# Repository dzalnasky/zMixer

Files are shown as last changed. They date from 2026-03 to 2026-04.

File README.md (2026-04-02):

# zMixer
zMixer is a USB-C programmable, 0-4GHz IF to 5-10.4GHz RF upconverting/downconverting RF mixer with dedicated LO chip generating 0-6.4GHz. Perfect for radios with operating frequencies up to 4GHz that want to work with higher frequency bands. 
# Key Components
* Texas Instruments LMX2572 Frequency Synthesizer
  * Drop in replacements include the LMX2592 (up to 9.8GHz), LMX2594 (up to 15GHz), and LMX2595 (up to 20GHz) for higher LO frequency generation **(May require different RF mixer IC)*
* Microchip MCP2210 USB to SPI Interface
* Analog Devices HMC220B RF Mixer
  * Drop in replacement includes HMC218B (3.5-8GHz RF/LO, 1.5GHz IF)
# Block Diagram

# Schematic


# PCB
pcb_3d

pcb_2d

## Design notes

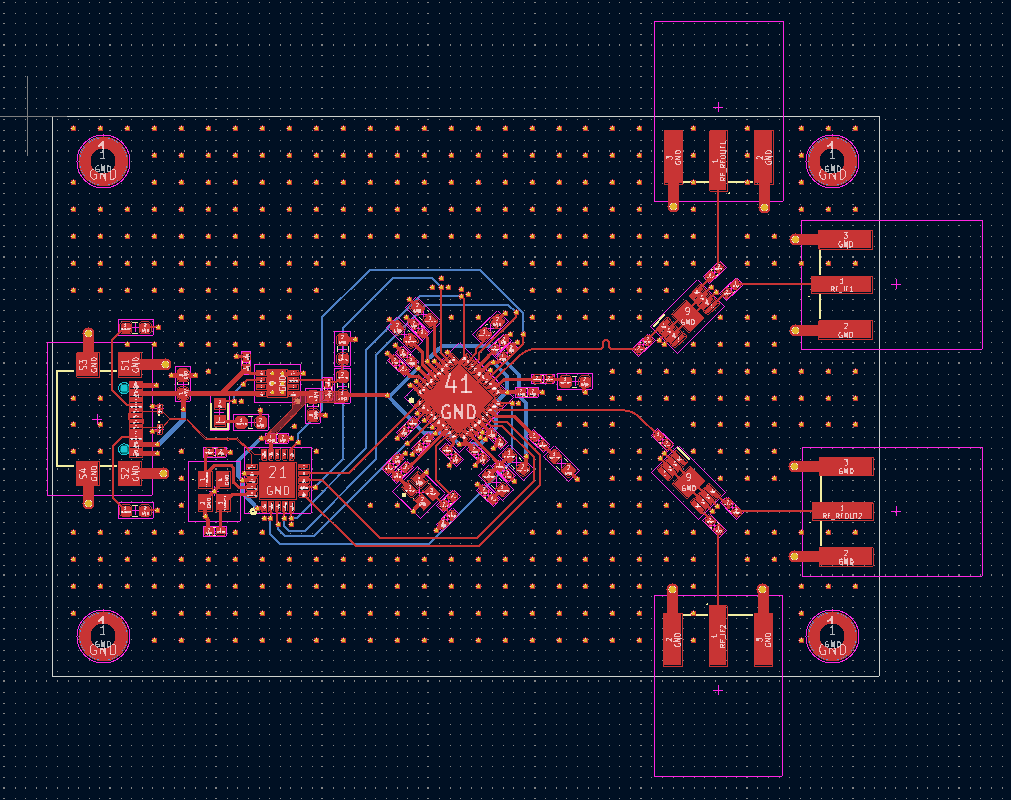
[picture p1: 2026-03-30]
Mixer_KiCAD/Mixer/pcb_2d.PNG

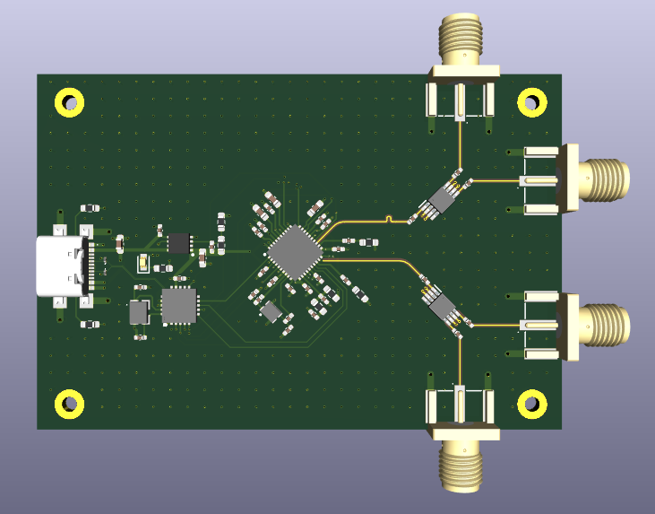
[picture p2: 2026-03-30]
Mixer_KiCAD/Mixer/pcb_3d.PNG

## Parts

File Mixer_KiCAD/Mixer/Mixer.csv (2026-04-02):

Reference | Qty | Value | DNP | Exclude from BOM | Exclude from Board | Footprint | Datasheet | Distributor Link | MPN
C1,C11,C12,C19 | 4 | 100n |  |  |  | Capacitor_SMD:C_0402_1005Metric_Pad0.74x0.62mm_HandSolder | https://www.mouser.com/datasheet/3/76/2/GRM155R70J104KA01_01A.pdf | https://www.mouser.com/ProductDetail/Murata-Electronics/GRM155R70J104KA01D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 | GRM155R70J104KA01D
C2,C3,C4,C5,C6,C7,C13,C16 | 8 | 20p |  |  |  | Capacitor_SMD:C_0402_1005Metric_Pad0.74x0.62mm_HandSolder | https://pim.murata.com/asset/pim4/ceramicCapacitorSMD/GCM1555C1H200JA16-01A-EN_PDF_CERAMICCAPACITORSMD | https://www.mouser.com/ProductDetail/Murata-Electronics/GCM1555C1H200JA16D | GCM1555C1H200JA16D
C8,C9,C10,C24,C31 | 5 | 1u |  |  |  | Capacitor_SMD:C_0402_1005Metric_Pad0.74x0.62mm_HandSolder | https://www.mouser.com/datasheet/3/76/2/GRT155C80J105KE01_01A.pdf | https://www.mouser.com/ProductDetail/Murata-Electronics/GRT155C80J105KE01D | GRT155C80J105KE01D
C14 | 1 | 560p |  |  |  | Capacitor_SMD:C_0402_1005Metric_Pad0.74x0.62mm_HandSolder | https://datasheets.kyocera-avx.com/KGM_X7R.pdf | https://www.mouser.com/ProductDetail/KYOCERA-AVX/04026C681KAT2A | 04026C681KAT2A
C15 | 1 | 1n5 |  |  |  | Capacitor_SMD:C_0402_1005Metric_Pad0.74x0.62mm_HandSolder | https://pim.murata.com/asset/pim4/ceramicCapacitorSMD/GRM1555C1H152GA01-01A-EN_PDF_CERAMICCAPACITORSMD | https://www.mouser.com/ProductDetail/Murata-Electronics/GRM1555C1H152GA01D | GRM1555C1H152GA01D
C17 | 1 | 120n |  |  |  | Capacitor_SMD:C_0402_1005Metric_Pad0.74x0.62mm_HandSolder | https://www.mouser.com/datasheet/3/76/3/GRM155R61A124ME19_01A.pdf | https://www.mouser.com/ProductDetail/Murata-Electronics/GRM155R61A124ME19D | GRM155R61A124ME19D
C18,C21,C23,C30,C33 | 5 | 10u |  |  |  | Capacitor_SMD:C_0603_1608Metric_Pad1.08x0.95mm_HandSolder | https://www.mouser.com/datasheet/3/76/2/GRM188R60J106ME47_61A.pdf | https://www.mouser.com/ProductDetail/Murata-Electronics/GRM188R60J106ME47D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 | GRM188R60J106ME47D
C20,C29 | 2 | 470n |  |  |  | Capacitor_SMD:C_0402_1005Metric_Pad0.74x0.62mm_HandSolder | https://www.mouser.com/datasheet/3/76/3/GRM155R61H474ME11_01A.pdf | https://www.mouser.com/ProductDetail/Murata-Electronics/GRM155R61H474ME11D | GRM155R61H474ME11D
C22,C32 | 2 | 10n |  |  |  | Capacitor_SMD:C_0402_1005Metric_Pad0.74x0.62mm_HandSolder | https://www.mouser.com/datasheet/3/76/1/GRM155R71E103JA01-01A.pdf | https://www.mouser.com/ProductDetail/Murata-Electronics/GRM155R71E103JA01J | GRM155R71E103JA01J
C25,C26 | 2 | 3n |  |  |  | Capacitor_SMD:C_0402_1005Metric_Pad0.74x0.62mm_HandSolder | https://pim.murata.com/asset/pim4/ceramicCapacitorSMD/GRM1557U1A302JA01-01A-EN_PDF_CERAMICCAPACITORSMD | https://www.mouser.com/ProductDetail/Murata-Electronics/GRM1557U1A302JA01D?qs=MY6wChARw2y70SmNRdypAQ%3D%3D | GRM1557U1A302JA01D
C27,C28 | 2 | 4p |  |  |  | Capacitor_SMD:C_0402_1005Metric_Pad0.74x0.62mm_HandSolder | https://pim.murata.com/asset/pim4/ceramicCapacitorSMD/GCM1555C1H4R0BA16-01A-EN_PDF_CERAMICCAPACITORSMD | https://www.mouser.com/ProductDetail/Murata-Electronics/GCM1555C1H4R0BA16J | GCM1555C1H4R0BA16J
C34,C35 | 2 | 10p |  |  |  | Capacitor_SMD:C_0402_1005Metric_Pad0.74x0.62mm_HandSolder | https://pim.murata.com/asset/pim4/ceramicCapacitorSMD/GCM1555C1H100JA16-01A-EN_PDF_CERAMICCAPACITORSMD | https://www.mouser.com/ProductDetail/Murata-Electronics/GCM1555C1H100JA16J | GCM1555C1H100JA16J
D1,D2 | 2 | ESD8472MUT5G |  |  |  | SamacSys_Parts:X3DFN2-CASE152AF-ISSUE-A | https://www.onsemi.com/pub/Collateral/ESD8472-D.PDF | https://www.mouser.com/ProductDetail/onsemi/ESD8472MUT5G?qs=72ObqG5T4UZT1i%252BIC5Pouw%3D%3D | ESD8472MUT5G
H1,H2,H3,H4 | 4 | MountingHole_Pad |  | Excluded from BOM |  | MountingHole:MountingHole_2.2mm_M2_Pad_TopBottom | ~
IC1,IC3 | 2 | HMC220BMS8GETR |  |  |  | SamacSys_Parts:SOP65P490X110-9N | https://www.analog.com/media/en/technical-documentation/data-sheets/HMC220B.pdf | https://www.analog.com/HMC220B/datasheet | HMC220BMS8GETR
IC2 | 1 | LMX2572RHAT |  |  |  | SamacSys_Parts:QFN50P600X600X100-41N-D | http://www.ti.com/lit/gpn/lmx2572 | https://www.mouser.com/ProductDetail/Texas-Instruments/LMX2572RHAR?qs=j%252B1pi9TdxUZ5mDySBseH5A%3D%3D | LMX2572RHAR
IC4 | 1 | TPS74601PQWDRBRQ1 |  |  |  | SamacSys_Parts:SON65P300X300X100-9N-D | https://www.ti.com/lit/ds/symlink/tps746-q1.pdf?ts=1625472063654 | https://www.mouser.com/ProductDetail/Texas-Instruments/TPS74601PQWDRBRQ1 | TPS74601PQWDRBRQ1
IC5 | 1 | MCP2210-I_MQ |  |  |  | SamacSys_Parts:QFN65P500X500X100-21N-D | https://www.mouser.com/datasheet/3/282/1/MCP2210-Data-Sheet-DS20002288.pdf | https://www.mouser.com/ProductDetail/Microchip-Technology/MCP2210-I-MQ?qs=hort8UWU32pLWgskQOyvyg%3D%3D | MCP2210-I/MQ
J1,J2,J3,J4 | 4 | CONSMA020.062-G |  |  |  | SamacSys_Parts:CONSMA020062G | https://componentsearchengine.com/Datasheets/1/CONSMA020.062-G.pdf | https://www.mouser.com/ProductDetail/TE-Connectivity-Linx-Technologies/CONSMA020.062-G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 | CONSMA020.062-G
J5 | 1 | USB4940-00-A |  |  |  | SamacSys_Parts:USB494000A | https://gct.co/download?type=PDFDrawing&name=USB4940.pdf | https://www.mouser.com/ProductDetail/GCT/USB4940-00-A?qs=vcFyY%252BOcAyjpPzN1Hxr%2FVw%3D%3D | USB4940-00-A
LED1 | 1 | SML-D12U1WT86 |  |  |  | SamacSys_Parts:LEDC1608X65N | https://componentsearchengine.com/Datasheets/1/SML-D12U1WT86.pdf | https://www.mouser.com/ProductDetail/ROHM-Semiconductor/SML-D12U1WT86 | SML-D12U1WT86
R1,R2 | 2 | 50R |  |  |  | Resistor_SMD:R_0603_1608Metric_Pad0.98x0.95mm_HandSolder | https://www.vishay.com/doc?28758 | https://www.mouser.com/ProductDetail/Vishay/TNPW060350R0DEEA | TNPW060350R0DEEA
R3 | 1 | 330R |  |  |  | Resistor_SMD:R_0603_1608Metric_Pad0.98x0.95mm_HandSolder | https://www.vishay.com/doc?20132 | https://www.mouser.com/ProductDetail/Vishay/RCA0603330RFKEASR | RCA0603330RFKEASR
R4 | 1 | 120R |  |  |  | Resistor_SMD:R_0603_1608Metric_Pad0.98x0.95mm_HandSolder | https://www.vishay.com/doc?28952 | https://www.mouser.com/ProductDetail/Vishay-Beyschlag/MCT0603MC1200FP500 | MCT0603MC1200FP500
R5,R6 | 2 | 5k1 |  |  |  | Resistor_SMD:R_0603_1608Metric_Pad0.98x0.95mm_HandSolder | https://www.vishay.com/docs/20035/dcrcwe3.pdf | https://www.mouser.com/ProductDetail/Vishay/CRCW06035K10FKEBC | CRCW06035K10FKEBC
R7 | 1 | 1M |  |  |  | Resistor_SMD:R_0603_1608Metric_Pad0.98x0.95mm_HandSolder | https://www.vishay.com/docs/20035/dcrcwe3.pdf | https://www.mouser.com/ProductDetail/Vishay/CRCW06031M00FKEAC | CRCW06031M00FKEAC
R8 | 1 | 140R |  |  |  | Resistor_SMD:R_0603_1608Metric_Pad0.98x0.95mm_HandSolder | https://www.vishay.com/docs/20035/dcrcwe3.pdf | https://www.mouser.com/ProductDetail/Vishay/CRCW0603140RFKEAC | CRCW0603140RFKEAC
R9 | 1 | 200k |  |  |  | Resistor_SMD:R_0603_1608Metric_Pad0.98x0.95mm_HandSolder | https://www.vishay.com/docs/20035/dcrcwe3.pdf | https://www.mouser.com/ProductDetail/Vishay/CRCW0603200KFKEBC | CRCW0603200KFKEBC
Y1 | 1 | ABM10W-50.0000MHZ-4-D1X-T3 |  |  |  | SamacSys_Parts:ABM10W240000MHZ8K1ZT3 | https://www.mouser.com/datasheet/3/184/1/ABM10W.pdf | https://www.mouser.com/ProductDetail/ABRACON/ABM10W-50.0000MHZ-4-D1X-T3?qs=5aG0NVq1C4yqd2TM%2F89nsQ%3D%3D | ABM10W-50.0000MHZ-4-D1X-T3
Y2 | 1 | ABM8G-12.000MHZ-18-D2Y-T |  |  |  | SamacSys_Parts:ABM8G12000MHZ18D2YT | https://www.mouser.com/datasheet/3/184/1/ABM8G.pdf | https://www.mouser.com/ProductDetail/ABRACON/ABM8G-12.000MHZ-18-D2Y-T?qs=3LVMET7lfiMArGND0L1Ksw%3D%3D | ABM8G-12.000MHZ-18-D2Y-T

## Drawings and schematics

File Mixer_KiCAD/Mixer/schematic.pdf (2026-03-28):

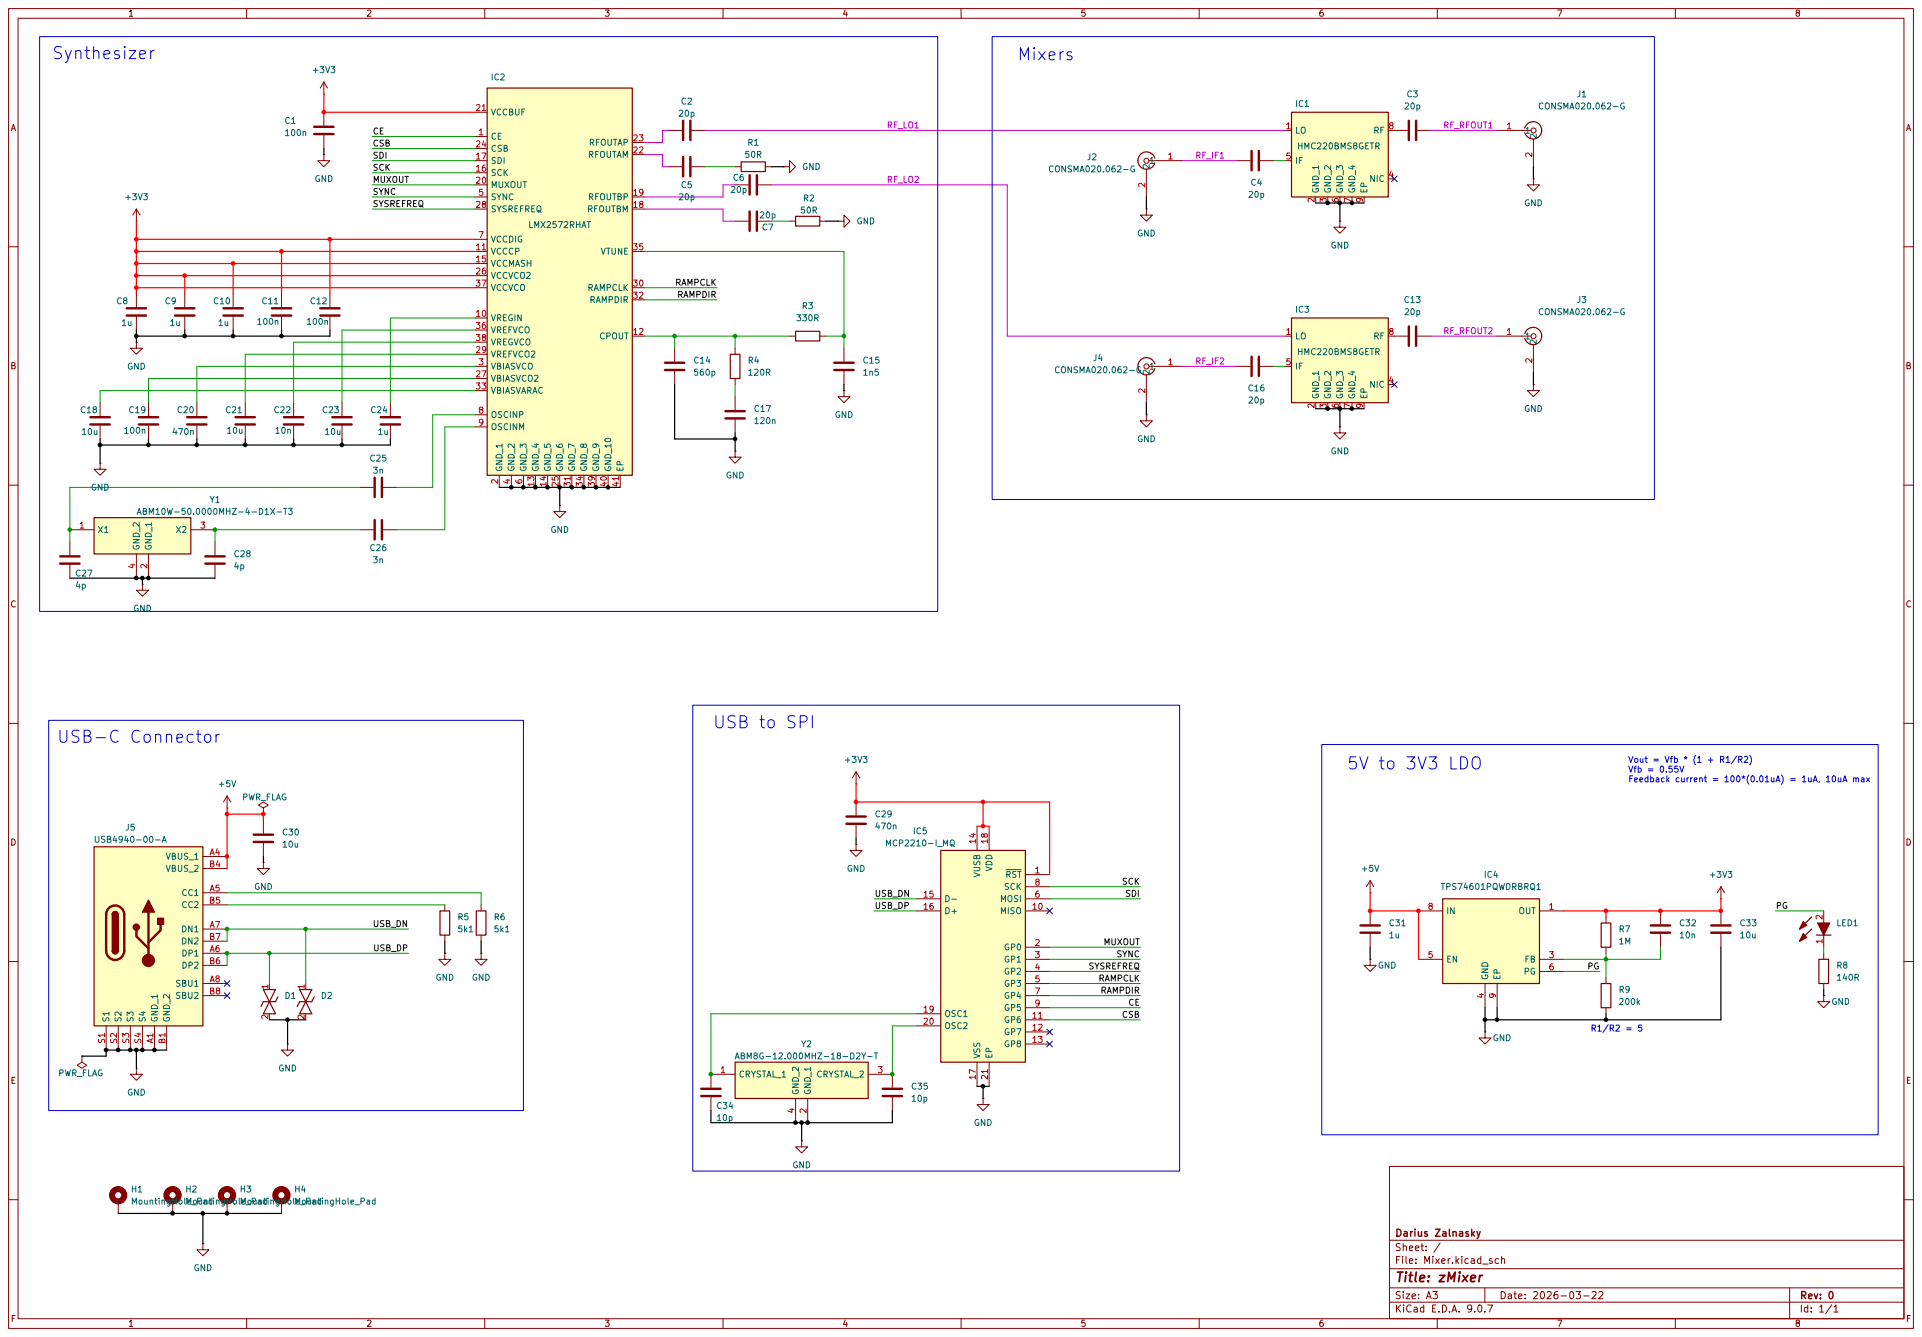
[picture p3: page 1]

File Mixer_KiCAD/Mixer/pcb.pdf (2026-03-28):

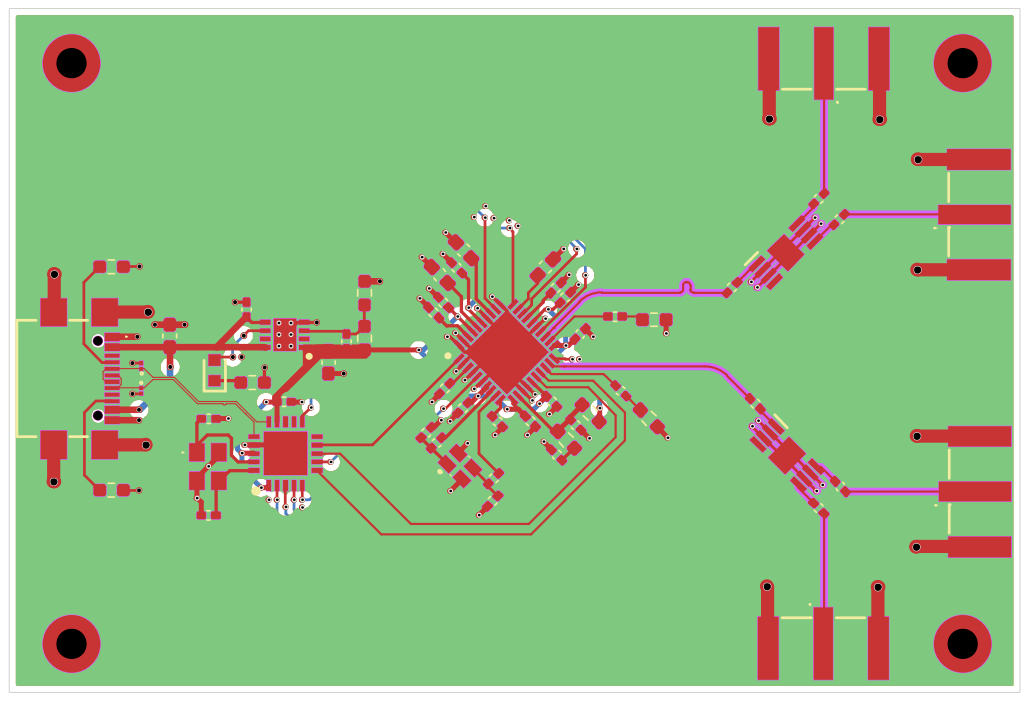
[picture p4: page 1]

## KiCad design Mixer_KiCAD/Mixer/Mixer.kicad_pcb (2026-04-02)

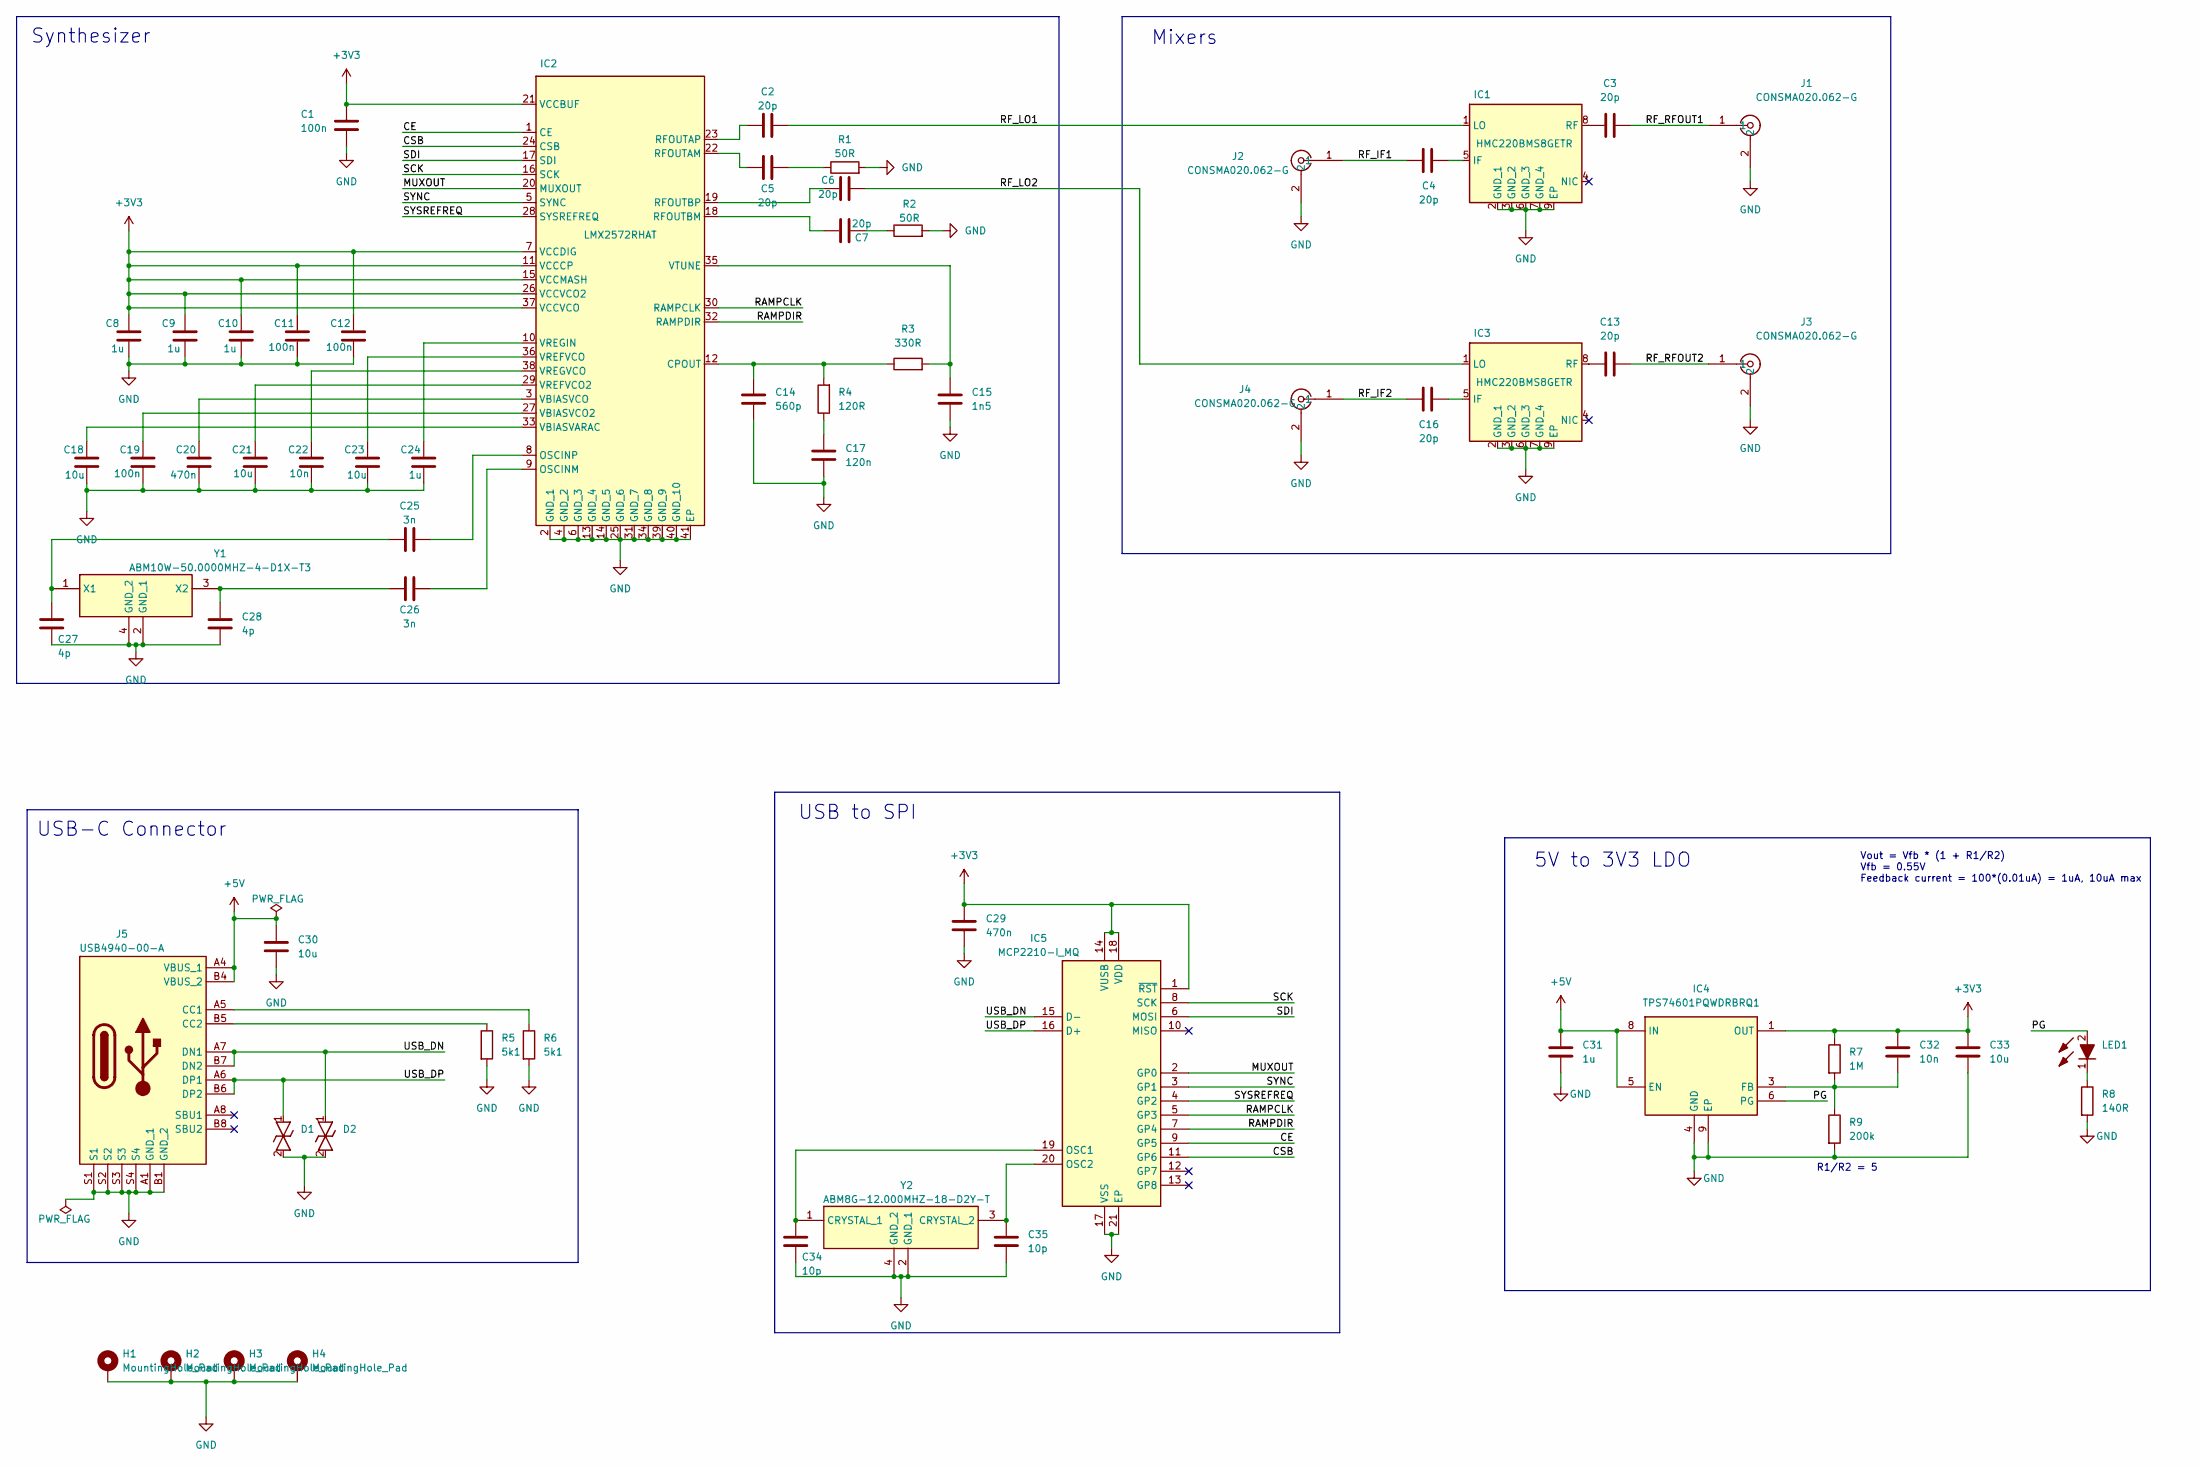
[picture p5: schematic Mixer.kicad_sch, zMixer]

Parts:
C1, C11, C12, C19: 100n; C_0402_1005Metric_Pad0.74x0.62mm_HandSolder; Voltage/Current Rating 6.3V
C2, C3, C4, C5, C6, C7, C13, C16: 20p; C_0402_1005Metric_Pad0.74x0.62mm_HandSolder
C8, C9, C10, C24: 1u; C_0402_1005Metric_Pad0.74x0.62mm_HandSolder; Voltage/Current Rating 6.3V
C14: 560p; C_0402_1005Metric_Pad0.74x0.62mm_HandSolder; Voltage/Current Rating 6.3V
C15: 1n5; C_0402_1005Metric_Pad0.74x0.62mm_HandSolder; Voltage/Current Rating 6.3V
C17: 120n; C_0402_1005Metric_Pad0.74x0.62mm_HandSolder; Voltage/Current Rating 6.3V
C18, C21, C23, C30: 10u; C_0603_1608Metric_Pad1.08x0.95mm_HandSolder; Voltage/Current Rating 6.3V
C20: 470n; C_0402_1005Metric_Pad0.74x0.62mm_HandSolder; Voltage/Current Rating 6.3V
C22: 10n; C_0402_1005Metric_Pad0.74x0.62mm_HandSolder; Voltage/Current Rating 6.3V
C25, C26: 3n; C_0402_1005Metric_Pad0.74x0.62mm_HandSolder
C27, C28: 4p; C_0402_1005Metric_Pad0.74x0.62mm_HandSolder
C29: 470n; C_0402_1005Metric_Pad0.74x0.62mm_HandSolder
C31: 1u; C_0402_1005Metric_Pad0.74x0.62mm_HandSolder
C32: 10n; C_0402_1005Metric_Pad0.74x0.62mm_HandSolder
C33: 10u; C_0603_1608Metric_Pad1.08x0.95mm_HandSolder
C34, C35: 10p; C_0402_1005Metric_Pad0.74x0.62mm_HandSolder
D1, D2: ESD8472MUT5G; X3DFN2-CASE152AF-ISSUE-A; Mouser Part Number 863-ESD8472MUT5G
H1, H2, H3, H4: MountingHole_Pad; MountingHole_2.2mm_M2_Pad_TopBottom
IC1, IC3: HMC220BMS8GETR; SOP65P490X110-9N; Manufacturer_Part_Number HMC220BMS8GETR; Mouser Part Number 584-HMC220BMS8GETR
IC2: LMX2572RHAT; QFN50P600X600X100-41N-D; Mouser Part Number 595-LMX2572RHAT
IC4: TPS74601PQWDRBRQ1; SON65P300X300X100-9N-D; Manufacturer_Part_Number TPS74601PQWDRBRQ1
IC5: MCP2210-I_MQ; QFN65P500X500X100-21N-D; Mouser Part Number 579-MCP2210IMQ
J1, J2, J3, J4: CONSMA020.062-G; CONSMA020062G; Mouser Part Number 712-CONSMA020.062-G
J5: USB4940-00-A; USB494000A; Manufacturer_Part_Number USB4940-00-A
LED1: SML-D12U1WT86; LEDC1608X65N; Mouser Part Number 755-SML-D12U1WT86
R1, R2: 50R; R_0603_1608Metric_Pad0.98x0.95mm_HandSolder
R3: 330R; R_0603_1608Metric_Pad0.98x0.95mm_HandSolder
R4: 120R; R_0603_1608Metric_Pad0.98x0.95mm_HandSolder
R5, R6: 5k1; R_0603_1608Metric_Pad0.98x0.95mm_HandSolder
R7: 1M; R_0603_1608Metric_Pad0.98x0.95mm_HandSolder
R8: 140R; R_0603_1608Metric_Pad0.98x0.95mm_HandSolder
R9: 200k; R_0603_1608Metric_Pad0.98x0.95mm_HandSolder
Y1: ABM10W-50.0000MHZ-4-D1X-T3; ABM10W240000MHZ8K1ZT3; Mouser Part Number 815-10W50-4D1XT
Y2: ABM8G-12.000MHZ-18-D2Y-T; ABM8G12000MHZ18D2YT; Mouser Part Number 815-ABM8G-12-18D2Y

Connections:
+3V3: C1.1, C8.1, C9.1, C10.1, C11.1, C12.1, C29.1, C32.1, C33.1, IC2.7 (VCCDIG), IC2.11 (VCCCP), IC2.15 (VCCMASH), IC2.21 (VCCBUF), IC2.26 (VCCVCO2), IC2.37 (VCCVCO), IC4.1 (OUT), IC5.1 (~RST), IC5.14 (VUSB), IC5.18 (VDD), R7.1
+5V: C30.1, C31.1, IC4.5 (EN), IC4.8 (IN), J5.A4 (VBUS_1), J5.B4 (VBUS_2)
/CE: IC2.1 (CE), IC5.9 (GP5)
/CSB: IC2.24 (CSB), IC5.11 (GP6)
/MUXOUT: IC2.20 (MUXOUT), IC5.2 (GP0)
/PG: IC4.6 (PG), LED1.2 (A)
/RAMPCLK: IC2.30 (RAMPCLK), IC5.5 (GP3)
/RAMPDIR: IC2.32 (RAMPDIR), IC5.7 (GP4)
/RF_IF1: C4.1, J2.1
/RF_IF2: C16.1, J4.1
/RF_LO1: C2.2, IC1.1 (LO)
/RF_LO2: C6.2, IC3.1 (LO)
/RF_RFOUT1: C3.2, J1.1
/RF_RFOUT2: C13.2, J3.1
/SCK: IC2.16 (SCK), IC5.8 (SCK)
/SDI: IC2.17 (SDI), IC5.6 (MOSI)
/SYNC: IC2.5 (SYNC), IC5.3 (GP1)
/SYSREFREQ: IC2.28 (SYSREFREQ), IC5.4 (GP2)
/USB_DN: D2.1, IC5.15 (D-), J5.A7 (DN1), J5.B7 (DN2)
/USB_DP: D1.1, IC5.16 (D+), J5.A6 (DP1), J5.B6 (DP2)
GND: C1.2, C8.2, C9.2, C10.2, C11.2, C12.2, C14.2, C15.2, C17.2, C18.2, C19.2, C20.2, C21.2, C22.2, C23.2, C24.2, C27.2, C28.2, C29.2, C30.2, C31.2, C33.2, C34.2, C35.2, D1.2, D2.2, H1.1, H2.1, H3.1, H4.1, IC1.2 (GND_1), IC1.3 (GND_2), IC1.6 (GND_3), IC1.7 (GND_4), IC1.9 (EP), IC2.2 (GND_1), IC2.4 (GND_2), IC2.6 (GND_3), IC2.13 (GND_4), IC2.14 (GND_5), IC2.25 (GND_6), IC2.31 (GND_7), IC2.34 (GND_8), IC2.39 (GND_9), IC2.40 (GND_10), IC2.41 (EP), IC3.2 (GND_1), IC3.3 (GND_2), IC3.6 (GND_3), IC3.7 (GND_4), IC3.9 (EP), IC4.4 (GND), IC4.9 (EP), IC5.17 (VSS), IC5.21 (EP), J1.2, J1.3, J2.2, J2.3, J3.2, J3.3, J4.2, J4.3, J5.A1 (GND_1), J5.B1 (GND_2), J5.S1, J5.S2, J5.S3, J5.S4, R1.2, R2.2, R5.2, R6.2, R8.2, R9.2, Y1.2 (GND_1), Y1.4 (GND_2), Y2.2 (GND_1), Y2.4 (GND_2)
unnamed: C5.2, R1.1
unnamed: C7.1, R2.1
unnamed: C17.1, R4.1
unnamed: C4.2, IC1.5 (IF)
unnamed: C3.1, IC1.8 (RF)
unnamed: C14.1, IC2.12 (CPOUT), R3.1, R4.2
unnamed: C26.2, IC2.9 (OSCINM)
unnamed: C25.2, IC2.8 (OSCINP)
unnamed: C5.1, IC2.22 (RFOUTAM)
unnamed: C2.1, IC2.23 (RFOUTAP)
unnamed: C7.2, IC2.18 (RFOUTBM)
unnamed: C6.1, IC2.19 (RFOUTBP)
unnamed: C18.1, IC2.33 (VBIASVARAC)
unnamed: C19.1, IC2.27 (VBIASVCO2)
unnamed: C20.1, IC2.3 (VBIASVCO)
unnamed: C21.1, IC2.29 (VREFVCO2)
unnamed: C23.1, IC2.36 (VREFVCO)
unnamed: C24.1, IC2.10 (VREGIN)
unnamed: C22.1, IC2.38 (VREGVCO)
unnamed: C15.1, IC2.35 (VTUNE), R3.2
unnamed: C16.2, IC3.5 (IF)
unnamed: C13.1, IC3.8 (RF)
unnamed: C32.2, IC4.3 (FB), R7.2, R9.1
unnamed: C34.1, IC5.19 (OSC1), Y2.1 (CRYSTAL_1)
unnamed: C35.1, IC5.20 (OSC2), Y2.3 (CRYSTAL_2)
unnamed: J5.A5 (CC1), R6.1
unnamed: J5.B5 (CC2), R5.1
unnamed: LED1.1 (K), R8.1
unnamed: C25.1, C27.1, Y1.1 (X1)
unnamed: C26.1, C28.1, Y1.3 (X2)

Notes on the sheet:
USB to SPI
Synthesizer
USB-C Connector
Mixers
Vout = Vfb * (1 + R1/R2) Vfb = 0.55V Feedback current = 100*(0.01uA) = 1uA, 10uA max
5V to 3V3 LDO
R1/R2 = 5

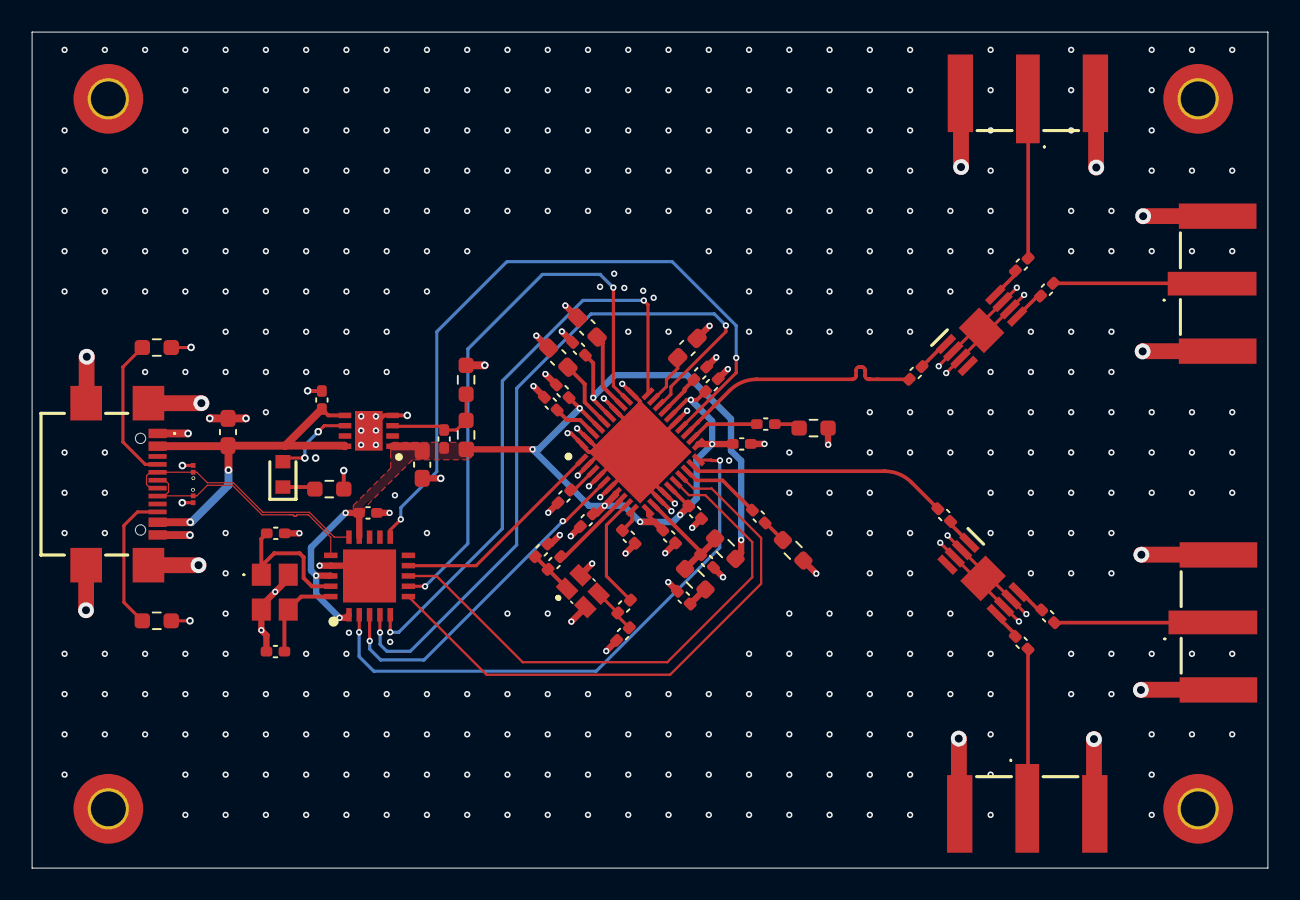
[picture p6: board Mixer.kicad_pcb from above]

Board: 4 copper layers, 78.0 x 52.7 mm, 63 parts (0 on the bottom side), 51 nets.

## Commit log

2026-03-27 updated gerbers. updated RF trace width
    [Mixer-B_Cu.gbr, Mixer-B_Mask.gbr, Mixer-B_Paste.gbr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]
2026-03-28 schematic, pcb pdfs, 3d pcb png
2026-03-30 added stitching vias to pcb
    [Mixer.kicad_pcb]
2026-04-02 adjusted RF trace width
    [Mixer-B_Cu.gbr, Mixer-B_Mask.gbr, Mixer-B_Paste.gbr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]
2026-04-02 updated BOM
    [Mixer.csv, Mixer.kicad_sch]
